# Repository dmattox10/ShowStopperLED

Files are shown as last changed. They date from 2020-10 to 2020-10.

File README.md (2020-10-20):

# ShowStopperLED
A five channel LED strip lighting Controller with serious audio reactivity and many display modes

The Android app communicates over Bluetooth 2.1 with the board, setting modes, and individual settings for each mode.
There is an audio input, which I was really impressed with myself for, because it introduced ZERO noise at all! The audio modes were my absolute favorite.

I stopped working on this project 7 years ago. I got mine working, as well as one for a friend, but a week after I got my prototypes in the mail and assembled them, the competitor released pretty much the same thing, ready for sale, and I gave up.

There are many different iterations, most untested, but the "defiance" version was built, and used successfully, including a $500 traffic ticket because I didn't realize it was on, and it was flashing "Red-Red", "Blue-Blue" on my car, and I got pulled over.

# An Apology: This was all completed and over, before I ever learned about Git!

## Android:
I've included every copy of the source code I have found in my old backups, I didn't compile and test any at this point, since I've switched to iOS personally, and don't have any Android devices lying around. I didn't use or have any apple equipment when I started the project.

## Boards:
I've included every version I made a board for, again, only "defiance" was produced in quantity and tested thoroughly.

## Arduino:
I started with an ATmega328P, moved to a PJRC Teensy 2.0, the code is a mess of files, and I can't tell which one is the "latest" version. The longest iterations are over 2k lines, pretty well commented.

## Media:
All of the files in this directory are photos of the equipment or advertising materials I came up with.

## Demo Links:
I recorded two videos with one of my best friends, of the ShowStopper working, on my 1993 Dodge Stealth.
- [Audio Modes](https://www.youtube.com/watch?v=f9GeiqDAIMo)
- [Motion Modes](https://www.youtube.com/watch?v=yMCRMerskfM)

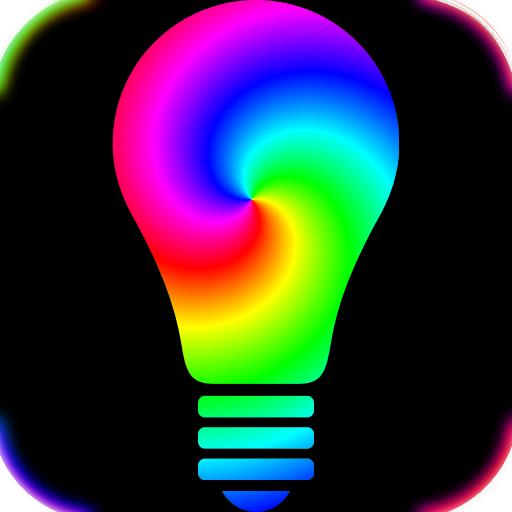
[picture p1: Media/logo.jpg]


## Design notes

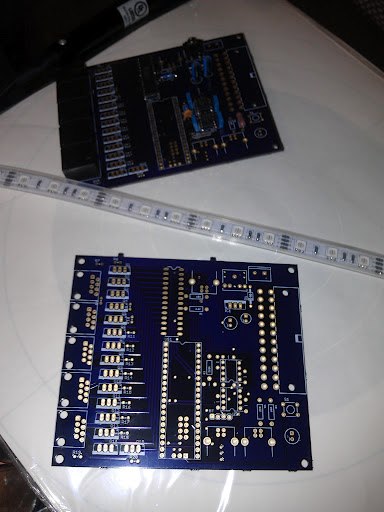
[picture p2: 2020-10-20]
Media/253186_10151097022037730_1391456851_n.jpg

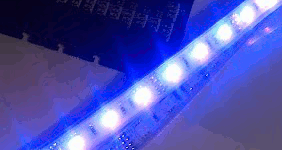
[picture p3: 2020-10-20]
Media/blue.gif

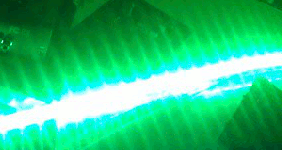
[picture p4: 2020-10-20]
Media/green.gif

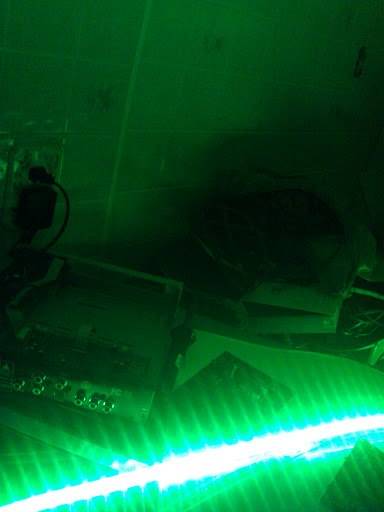
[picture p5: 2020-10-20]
Media/76591_10151097026597730_1787553381_n.jpg

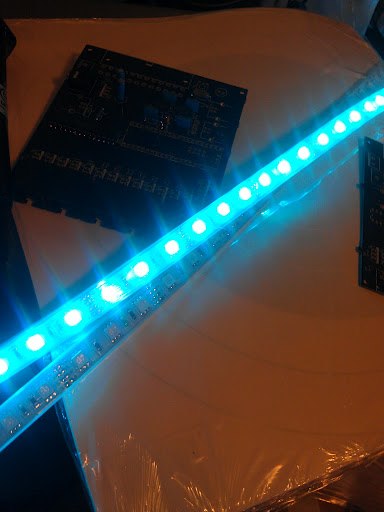
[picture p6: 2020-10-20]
Media/149688_10151097022222730_515309146_n.jpg

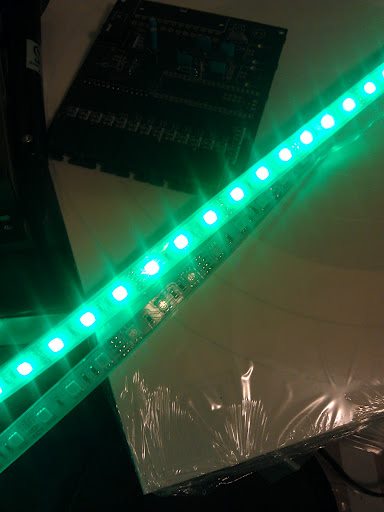
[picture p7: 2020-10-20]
Media/23940_10151097022192730_1112282240_n.jpg

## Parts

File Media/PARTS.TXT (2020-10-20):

Partlist

Exported from ShowStopper REV B.sch at 11/24/2012 2:46:44 PM

EAGLE Version 5.0.0 Copyright (c) 1988-2008 CadSoft

Part     Value                 Device                Package               Library  Sheet

C1       33pf                  CAP0603-CAP           0603-CAP              SparkFun 1
C2       .1uf                  CAP0603-CAP           0603-CAP              SparkFun 1
C3       .01uf                 CAP0603-CAP           0603-CAP              SparkFun 1
C4       .1uf                  CAP0603-CAP           0603-CAP              SparkFun 1
C5       100uf                 CAP_POLPTH1           CPOL-RADIAL-100UF-25V SparkFun 1
C6       10uf                  CAP_POLPTH2           CPOL-RADIAL-10UF-25V  SparkFun 1
C7       .1uf                  CAP0603-CAP           0603-CAP              SparkFun 1
C8       100uf                 CAP_POLPTH1           CPOL-RADIAL-100UF-25V SparkFun 1
C9       22PF                  CAP0805               0805                  SparkFun 1
C10      22PF                  CAP0805               0805                  SparkFun 1
C11      .1uf                  CAP0603-CAP           0603-CAP              SparkFun 1
C12      .1uf                  CAP0603-CAP           0603-CAP              SparkFun 1
C13      .1uf                  CAP0603-CAP           0603-CAP              SparkFun 1
C14      .1uf                  CAP0603-CAP           0603-CAP              SparkFun 1
D1       1N4004                DIODEPTH              DIODE-1N4001          SparkFun 1
EXT      RJ45-8PTH             RJ45-8PTH             RJ45-8                SparkFun 1
IC1      LM7805                V_REG_78XXSINK        TO220-IGO             SparkFun 1
IC2      AVR-MEGA8-PPTH        AVR-MEGA8-PPTH        DIL28-3               SparkFun 1
JP1      BT                    M04LOCK               1X04_LOCK             SparkFun 1
JP2                            M025MM                SCREWTERMINAL-5MM-2   SparkFun 1
JP8                            M06LONGPADS           1X06_LONGPADS         SparkFun 1
JP9                            M02LOCK               1X02_LOCK             SparkFun 1
JP10                           M02LOCK               1X02_LOCK             SparkFun 1
Q1                             MOSFET-NCHANNELPTH2   TO220V                SparkFun 1
Q2                             MOSFET-NCHANNELPTH2   TO220V                SparkFun 1
Q3                             MOSFET-NCHANNELPTH2   TO220V                SparkFun 1
Q4                             MOSFET-NCHANNELPTH2   TO220V                SparkFun 1
Q5                             MOSFET-NCHANNELPTH2   TO220V                SparkFun 1
Q6                             MOSFET-NCHANNELPTH2   TO220V                SparkFun 1
Q7                             MOSFET-NCHANNELPTH2   TO220V                SparkFun 1
Q8                             MOSFET-NCHANNELPTH2   TO220V                SparkFun 1
Q9                             MOSFET-NCHANNELPTH2   TO220V                SparkFun 1
Q10                            MOSFET-NCHANNELPTH2   TO220V                SparkFun 1
Q11                            MOSFET-NCHANNELPTH2   TO220V                SparkFun 1
Q12                            MOSFET-NCHANNELPTH2   TO220V                SparkFun 1
Q14                            MOSFET-NCHANNELPTH2   TO220V                SparkFun 1
Q13                            MOSFET-NCHANNELPTH2   TO220V                SparkFun 1
Q15                            MOSFET-NCHANNELPTH2   TO220V                SparkFun 1
R1       10k                   RESISTOR0805-RES      0805                  SparkFun 1
R2       10k                   RESISTOR0805-RES      0805                  SparkFun 1
R3       10k                   RESISTOR0603-RES      0603-RES              SparkFun 1
R4       10k                   RESISTOR0603-RES      0603-RES              SparkFun 1
R5       10k                   RESISTOR0603-RES      0603-RES              SparkFun 1
R6       10k                   RESISTOR0603-RES      0603-RES              SparkFun 1
R7       10k                   RESISTOR0603-RES      0603-RES              SparkFun 1
R8       10k                   RESISTOR0603-RES      0603-RES              SparkFun 1
R9       10k                   RESISTOR0603-RES      0603-RES              SparkFun 1
R10      10k                   RESISTOR0603-RES      0603-RES              SparkFun 1
R11      10k                   RESISTOR0603-RES      0603-RES              SparkFun 1
R12      10k                   RESISTOR0603-RES      0603-RES              SparkFun 1
R13      10k                   RESISTOR0603-RES      0603-RES              SparkFun 1
R14      10k                   RESISTOR0603-RES      0603-RES              SparkFun 1
R15      10k                   RESISTOR0603-RES      0603-RES              SparkFun 1
R16      10k                   RESISTOR0603-RES      0603-RES              SparkFun 1
R17      10k                   RESISTOR0603-RES      0603-RES              SparkFun 1
R18      200k                  RESISTOR0603-RES      0603-RES              SparkFun 1
R19      22k                   RESISTOR0603-RES      0603-RES              SparkFun 1
R20      22k                   RESISTOR0603-RES      0603-RES              SparkFun 1
R21      2.2K                  RESISTOR0805-RES      0805                  SparkFun 1
S1       SWITCH-MOMENTARY-2PTH SWITCH-MOMENTARY-2PTH TACTILE-PTH           SparkFun 1
U$1      MSGEQ7_PTH            MSGEQ7_PTH            DIL08                 SparkFun 1
U$3      RJ45-8PTH             RJ45-8PTH             RJ45-8                SparkFun 1
U$4      RJ45-8PTH             RJ45-8PTH             RJ45-8                SparkFun 1
U$5      RJ45-8PTH             RJ45-8PTH             RJ45-8                SparkFun 1
U$6      RJ45-8PTH             RJ45-8PTH             RJ45-8                SparkFun 1
U$7      RJ45-8PTH             RJ45-8PTH             RJ45-8                SparkFun 1
U1       AUD0                  AUDIO-JACKPTH         AUDIO-JACK            SparkFun 1
U2       TLC5940-NT            TLC5940-NT            DIL28-3               SparkFun 1
X1       USB_                  USB_                  USB-A-S-SILK-FEMALE   SparkFun 1
Y1       XTAL                  CRYSTALHC49UV         HC49U-V               SparkFun 1

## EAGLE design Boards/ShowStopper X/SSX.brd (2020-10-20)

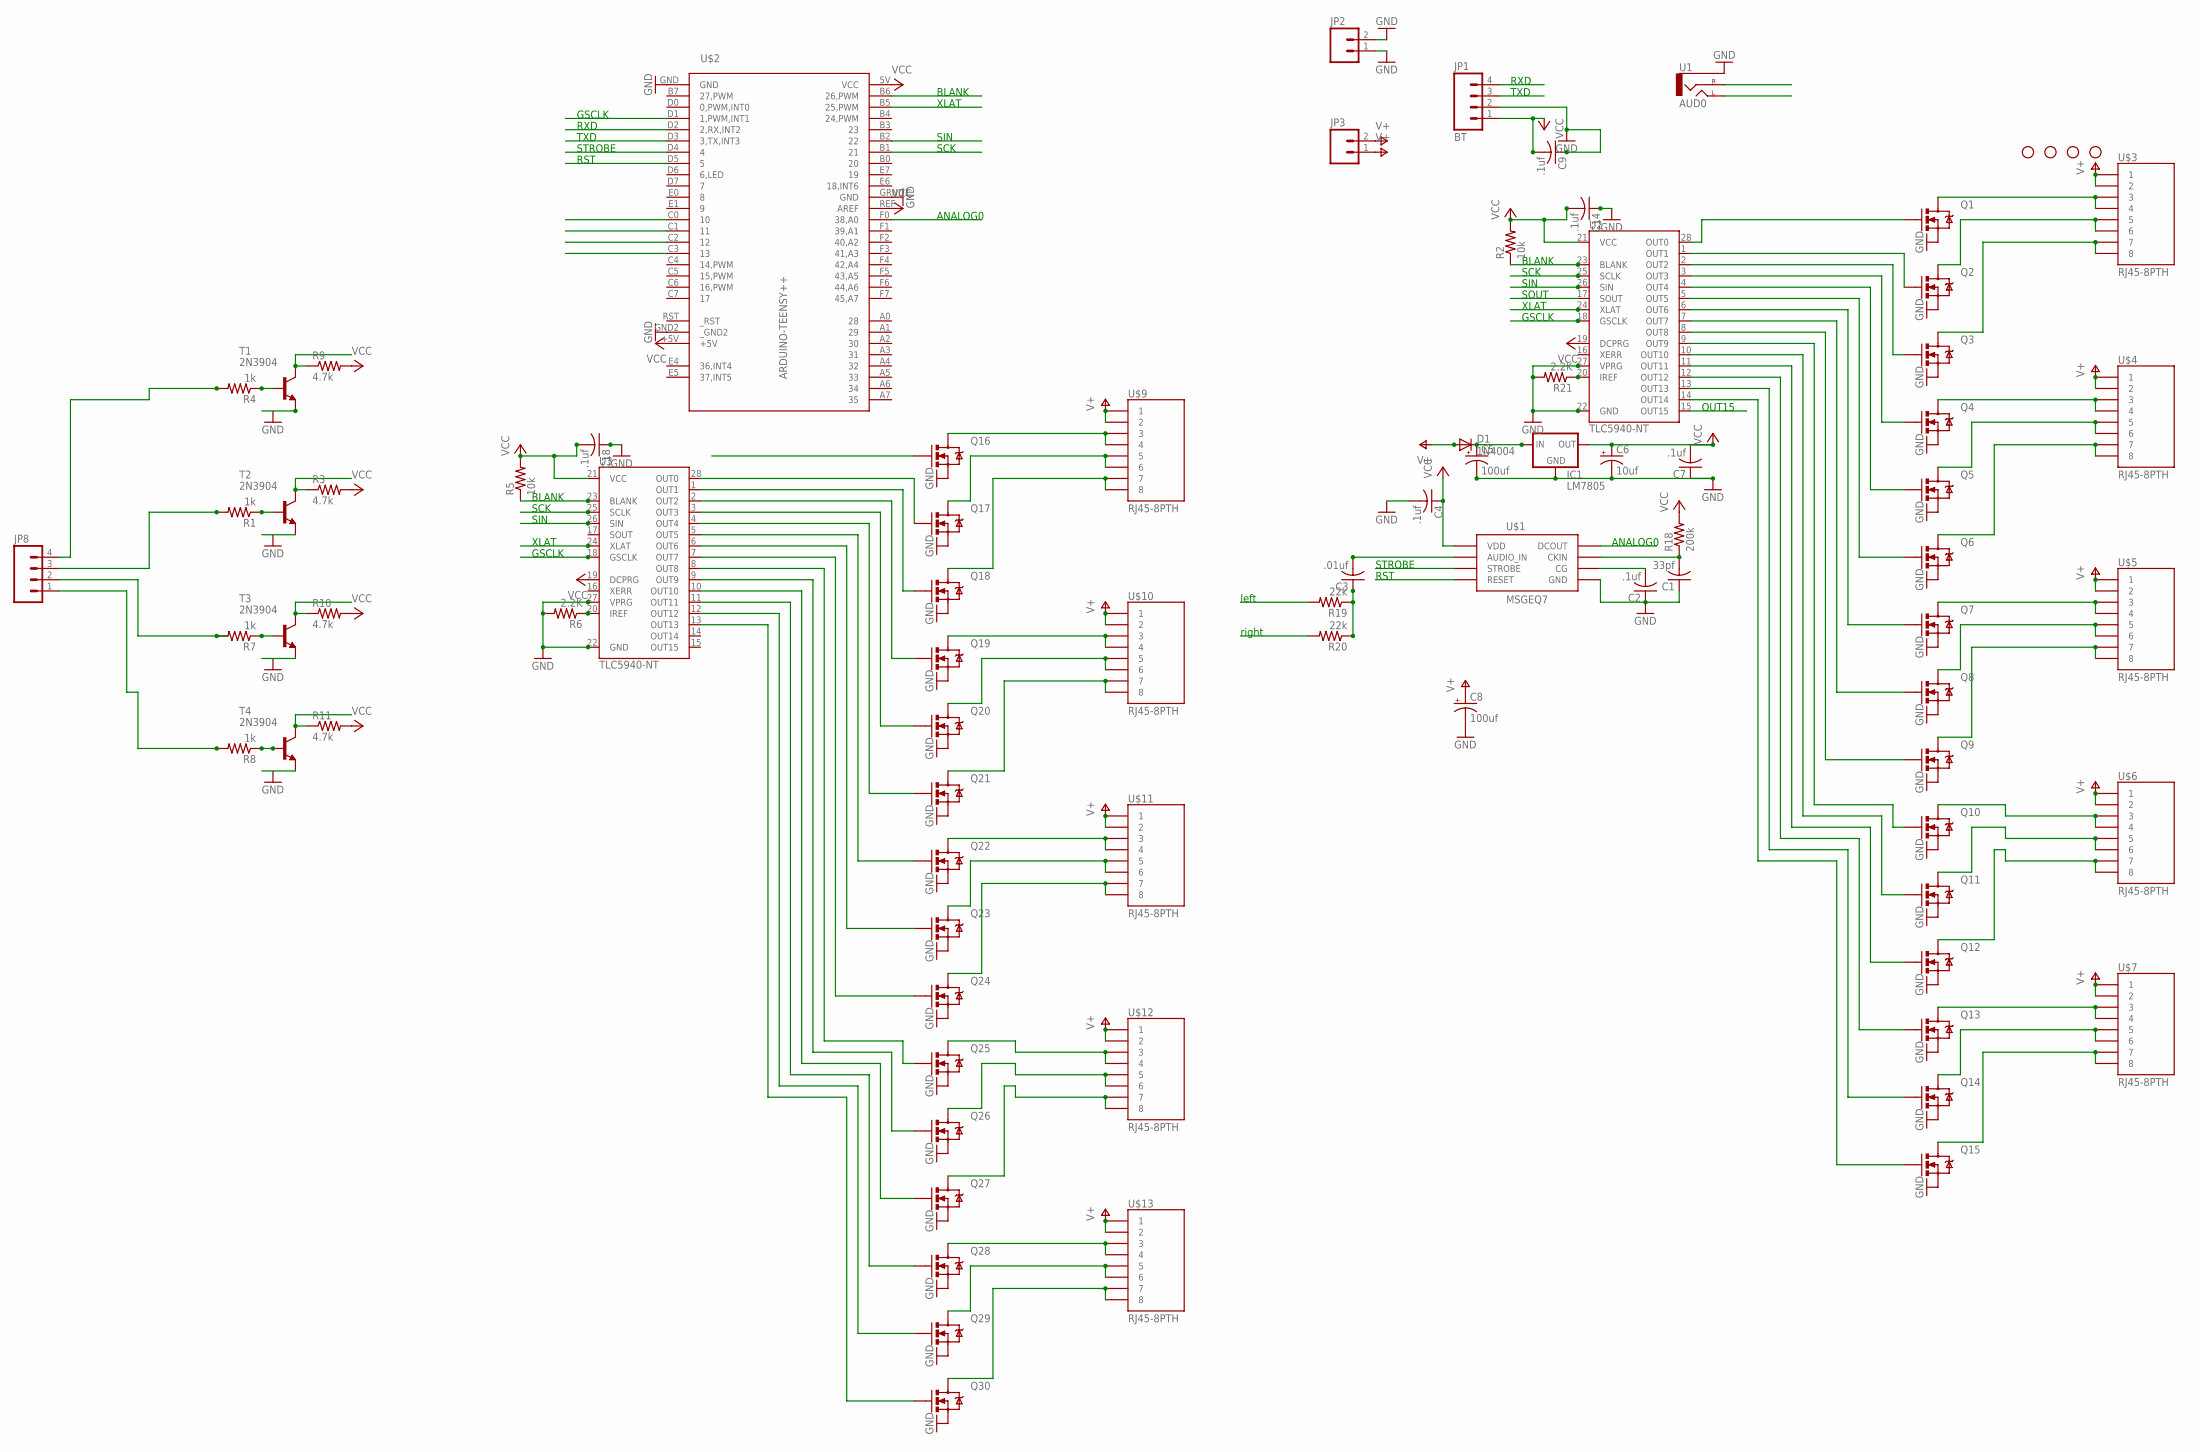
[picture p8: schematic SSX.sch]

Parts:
C1: 33pf; C025-025X050
C2, C4, C7, C9, C14, C18: .1uf; C025-025X050
C3: .01uf; C025-025X050
C5, C8: 100uf; CPOL-RADIAL-100UF-25V
C6: 10uf; CPOL-RADIAL-10UF-25V
D1: 1N4004; DIODE-1N4001
IC1: LM7805; TO220-IGO
JP1: BT; 1X04_LOCK
JP2, JP3: M025MM; SCREWTERMINAL-5MM-2
JP4, JP5, JP6, JP7: STAND-OFF
JP8: M04PTH; 1X04
Q1, Q2, Q3, Q4, Q5, Q6, Q7, Q8, Q9, Q10, Q11, Q12, Q13, Q14, Q15, Q16, Q17, Q18, Q19, Q20, Q21, Q22, Q23, Q24, Q25, Q26, Q27, Q28, Q29, Q30: MOSFET-NCHANNELPTH2; TO220V
R1, R4, R7, R8: 1k; 0207/2V
R2, R5: 10k; 0207/2V
R3, R9, R10, R11: 4.7k; 0207/2V
R6, R21: 2.2K; 0207/2V
R18: 200k; 0207/2V
R19, R20: 22k; 0207/2V
T1, T2, T3, T4: 2N3904; TO92
U1: AUD0; AUDIO-JACK
U2, U3: TLC5940-NT; DIL28-3
U$1: MSGEQ7_PTH; DIL08
U$2: ARDUINO-TEENSY++; TEENSY++
U$3, U$4, U$5, U$6, U$7, U$9, U$10, U$11, U$12, U$13: RJ45-8PTH; RJ45-8

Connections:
ANALOG0: U$1.3 (DCOUT), U$2.F0 (38,A0)
ARS: U$1.7 (RESET), U$2.D5 (5)
BL: R10.1, T3.1 (C), U$2.C1 (11)
BLANK: R2.1, U2.23 (BLANK), U$2.B6 (26,PWM)
BLANK1: R5.1, U3.23 (BLANK)
GND: C1.1, C2.1, C4.2, C5.2 (-), C6.2 (-), C7.1, C8.2 (-), C9.1, C14.1, C18.1, IC1.GND, JP1.2, JP2.1, JP2.2, Q1.3 (S), Q2.3 (S), Q3.3 (S), Q4.3 (S), Q5.3 (S), Q6.3 (S), Q7.3 (S), Q8.3 (S), Q9.3 (S), Q10.3 (S), Q11.3 (S), Q12.3 (S), Q13.3 (S), Q14.3 (S), Q15.3 (S), Q16.3 (S), Q17.3 (S), Q18.3 (S), Q19.3 (S), Q20.3 (S), Q21.3 (S), Q22.3 (S), Q23.3 (S), Q24.3 (S), Q25.3 (S), Q26.3 (S), Q27.3 (S), Q28.3 (S), Q29.3 (S), Q30.3 (S), R6.2, R21.2, U1.SLEEVE, U2.22 (GND), U2.27 (VPRG), U3.22 (GND), U3.27 (VPRG), U$1.2 (GND), U$2.GND, U$2.GND2 (_GND2), U$2.GRND1 (GND)
GSCLK: U2.18 (GSCLK), U$2.D1 (1,PWM,INT1)
GSCLK1: U3.18 (GSCLK)
HL: R11.1, T4.1 (C), U$2.C0 (10)
LEFT: R19.2, U1.TIP (LEFT)
LTS: R3.1, T2.1 (C), U$2.C2 (12)
unnamed: Q7.2 (D), U$5.3, U$5.4
unnamed: Q2.2 (D), U$3.5, U$3.6
unnamed: Q3.2 (D), U$3.7, U$3.8
unnamed: Q10.2 (D), U$6.3, U$6.4
unnamed: Q9.1 (G), U2.8 (OUT8)
unnamed: Q2.1 (G), U2.1 (OUT1)
unnamed: Q3.1 (G), U2.2 (OUT2)
unnamed: Q4.1 (G), U2.3 (OUT3)
unnamed: Q5.2 (D), U$4.5, U$4.6
unnamed: Q5.1 (G), U2.4 (OUT4)
unnamed: Q6.1 (G), U2.5 (OUT5)
unnamed: Q7.1 (G), U2.6 (OUT6)
unnamed: Q8.1 (G), U2.7 (OUT7)
unnamed: Q17.1 (G), U3.28 (OUT0)
unnamed: Q10.1 (G), U2.9 (OUT9)
unnamed: Q11.1 (G), U2.10 (OUT10)
unnamed: Q12.1 (G), U2.11 (OUT11)
unnamed: Q13.1 (G), U2.12 (OUT12)
unnamed: Q14.1 (G), U2.13 (OUT13)
unnamed: Q15.1 (G), U2.14 (OUT14)
unnamed: Q6.2 (D), U$4.7, U$4.8
unnamed: Q13.2 (D), U$7.3, U$7.4
unnamed: Q8.2 (D), U$5.5, U$5.6
unnamed: C1.2, R18.1, U$1.8 (CKIN)
unnamed: Q9.2 (D), U$5.7, U$5.8
unnamed: Q14.2 (D), U$7.5, U$7.6
unnamed: Q11.2 (D), U$6.5, U$6.6
unnamed: C3.2, U$1.5 (AUDIO_IN)
unnamed: Q12.2 (D), U$6.7, U$6.8
unnamed: Q15.2 (D), U$7.7, U$7.8
unnamed: Q1.2 (D), U$3.3, U$3.4
unnamed: C2.2, U$1.6 (CG)
unnamed: Q4.2 (D), U$4.3, U$4.4
unnamed: Q1.1 (G), U2.28 (OUT0)
unnamed: R21.1, U2.20 (IREF)
unnamed: C3.1, R19.1, R20.1
unnamed: Q18.1 (G), U3.1 (OUT1)
unnamed: Q19.1 (G), U3.2 (OUT2)
unnamed: Q20.1 (G), U3.3 (OUT3)
unnamed: C5.1 (+), D1.C, IC1.IN
unnamed: Q21.1 (G), U3.4 (OUT4)
unnamed: Q22.1 (G), U3.5 (OUT5)
unnamed: Q23.1 (G), U3.6 (OUT6)
unnamed: Q25.1 (G), U3.8 (OUT8)
unnamed: Q26.1 (G), U3.9 (OUT9)
unnamed: Q27.1 (G), U3.10 (OUT10)
unnamed: Q28.1 (G), U3.11 (OUT11)
unnamed: Q29.1 (G), U3.12 (OUT12)
unnamed: Q30.1 (G), U3.13 (OUT13)
unnamed: R1.1, T2.2 (B)
unnamed: Q17.2 (D), U$9.5, U$9.6
unnamed: Q18.2 (D), U$9.7, U$9.8
unnamed: Q20.2 (D), U$10.5, U$10.6
unnamed: Q21.2 (D), U$10.7, U$10.8
unnamed: Q23.2 (D), U$11.5, U$11.6
unnamed: Q24.2 (D), U$11.7, U$11.8
unnamed: Q26.2 (D), U$12.5, U$12.6
unnamed: Q27.2 (D), U$12.7, U$12.8
unnamed: Q16.2 (D), U$9.3, U$9.4
unnamed: Q19.2 (D), U$10.3, U$10.4
unnamed: Q22.2 (D), U$11.3, U$11.4
unnamed: Q25.2 (D), U$12.3, U$12.4
unnamed: Q28.2 (D), U$13.3, U$13.4
unnamed: Q29.2 (D), U$13.5, U$13.6
unnamed: Q30.2 (D), U$13.7, U$13.8
unnamed: R4.1, T1.2 (B)
unnamed: Q24.1 (G), U3.7 (OUT7)
unnamed: R6.1, U3.20 (IREF)
unnamed: R7.1, T3.2 (B)
unnamed: R8.1, T4.2 (B)
unnamed: JP8.4, R4.2
unnamed: JP8.3, R1.2
unnamed: JP8.2, R7.2
unnamed: JP8.1, R8.2
OUT15: Q16.1 (G), U2.15 (OUT15)
RIGHT: R20.2, U1.RING (RIGHT)
RTS: R9.1, T1.1 (C), U$2.C3 (13)
RXD: JP1.4, U$2.D3 (3,TX,INT3)
SCK: U2.25 (SCLK), U$2.B1 (21)
SCK1: U3.25 (SCLK)
SIN: U2.26 (SIN), U$2.B2 (22)
SOUT: U2.17 (SOUT), U3.26 (SIN)
STROBE: U$1.4 (STROBE), U$2.D4 (4)
TXD: JP1.3, U$2.D2 (2,RX,INT2)
V+: C8.1 (+), D1.A, JP3.1, JP3.2, U$3.1, U$3.2, U$4.1, U$4.2, U$5.1, U$5.2, U$6.1, U$6.2, U$7.1, U$7.2, U$9.1, U$9.2, U$10.1, U$10.2, U$11.1, U$11.2, U$12.1, U$12.2, U$13.1, U$13.2
VCC: C4.1, C6.1 (+), C7.2, C9.2, C14.2, C18.2, IC1.OUT, JP1.1, R2.2, R3.2, R5.2, R9.2, R10.2, R11.2, R18.2, U2.19 (DCPRG), U2.21 (VCC), U3.19 (DCPRG), U3.21 (VCC), U$1.1 (VDD), U$2.5V (VCC), U$2.+5V, U$2.REF (AREF)
XLAT: U2.24 (XLAT), U$2.B5 (25,PWM)
XLAT1: U3.24 (XLAT)

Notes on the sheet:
ANALOG0
RST
STROBE
left
right
SIN
SCK
XLAT
BLANK
GSCLK
RXD
TXD
SOUT
OUT15

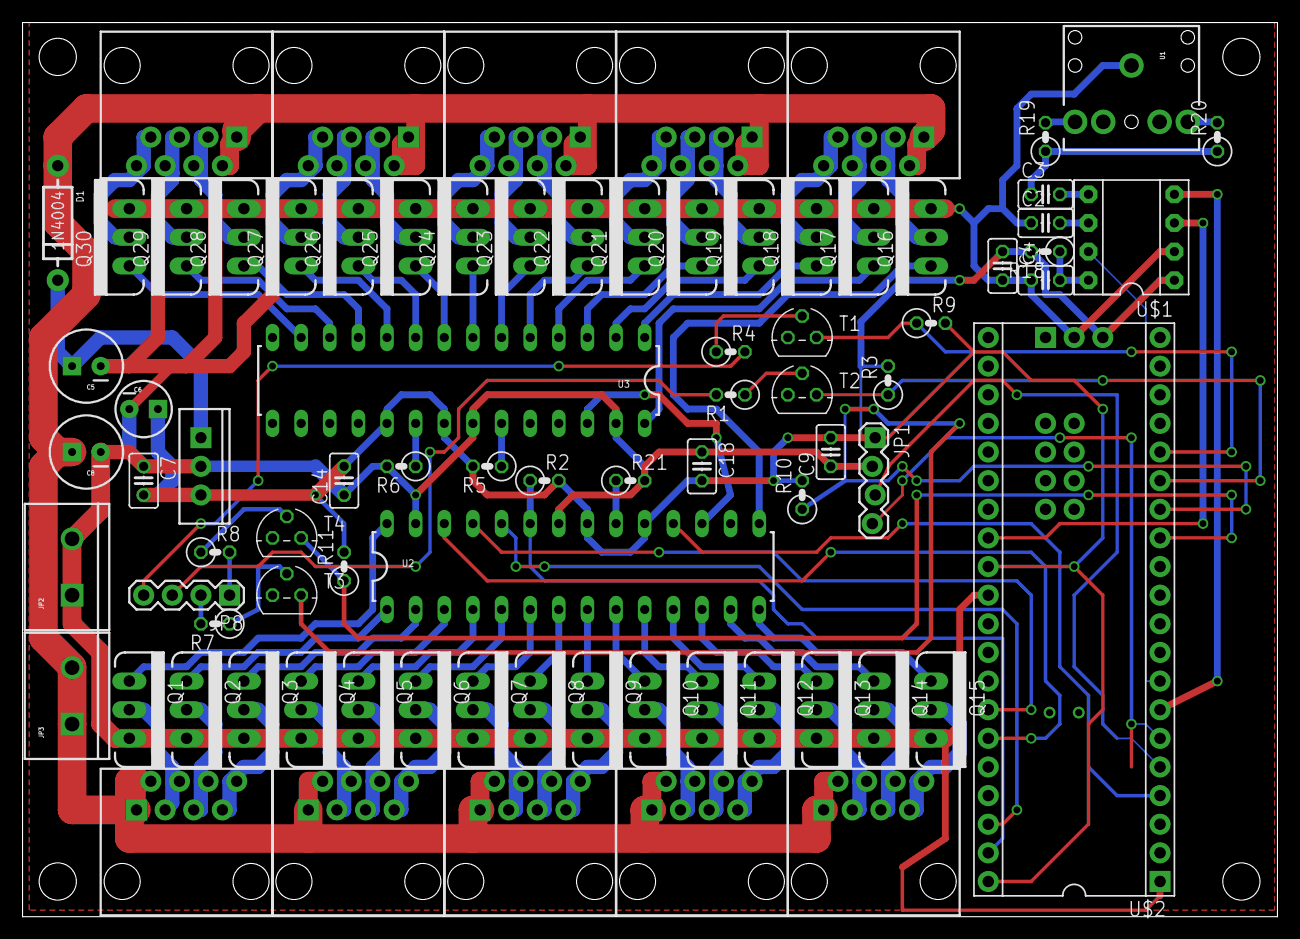
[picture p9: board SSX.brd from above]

Board: 2 copper layers, 111.3 x 79.3 mm, 85 parts (0 on the bottom side), 96 nets.

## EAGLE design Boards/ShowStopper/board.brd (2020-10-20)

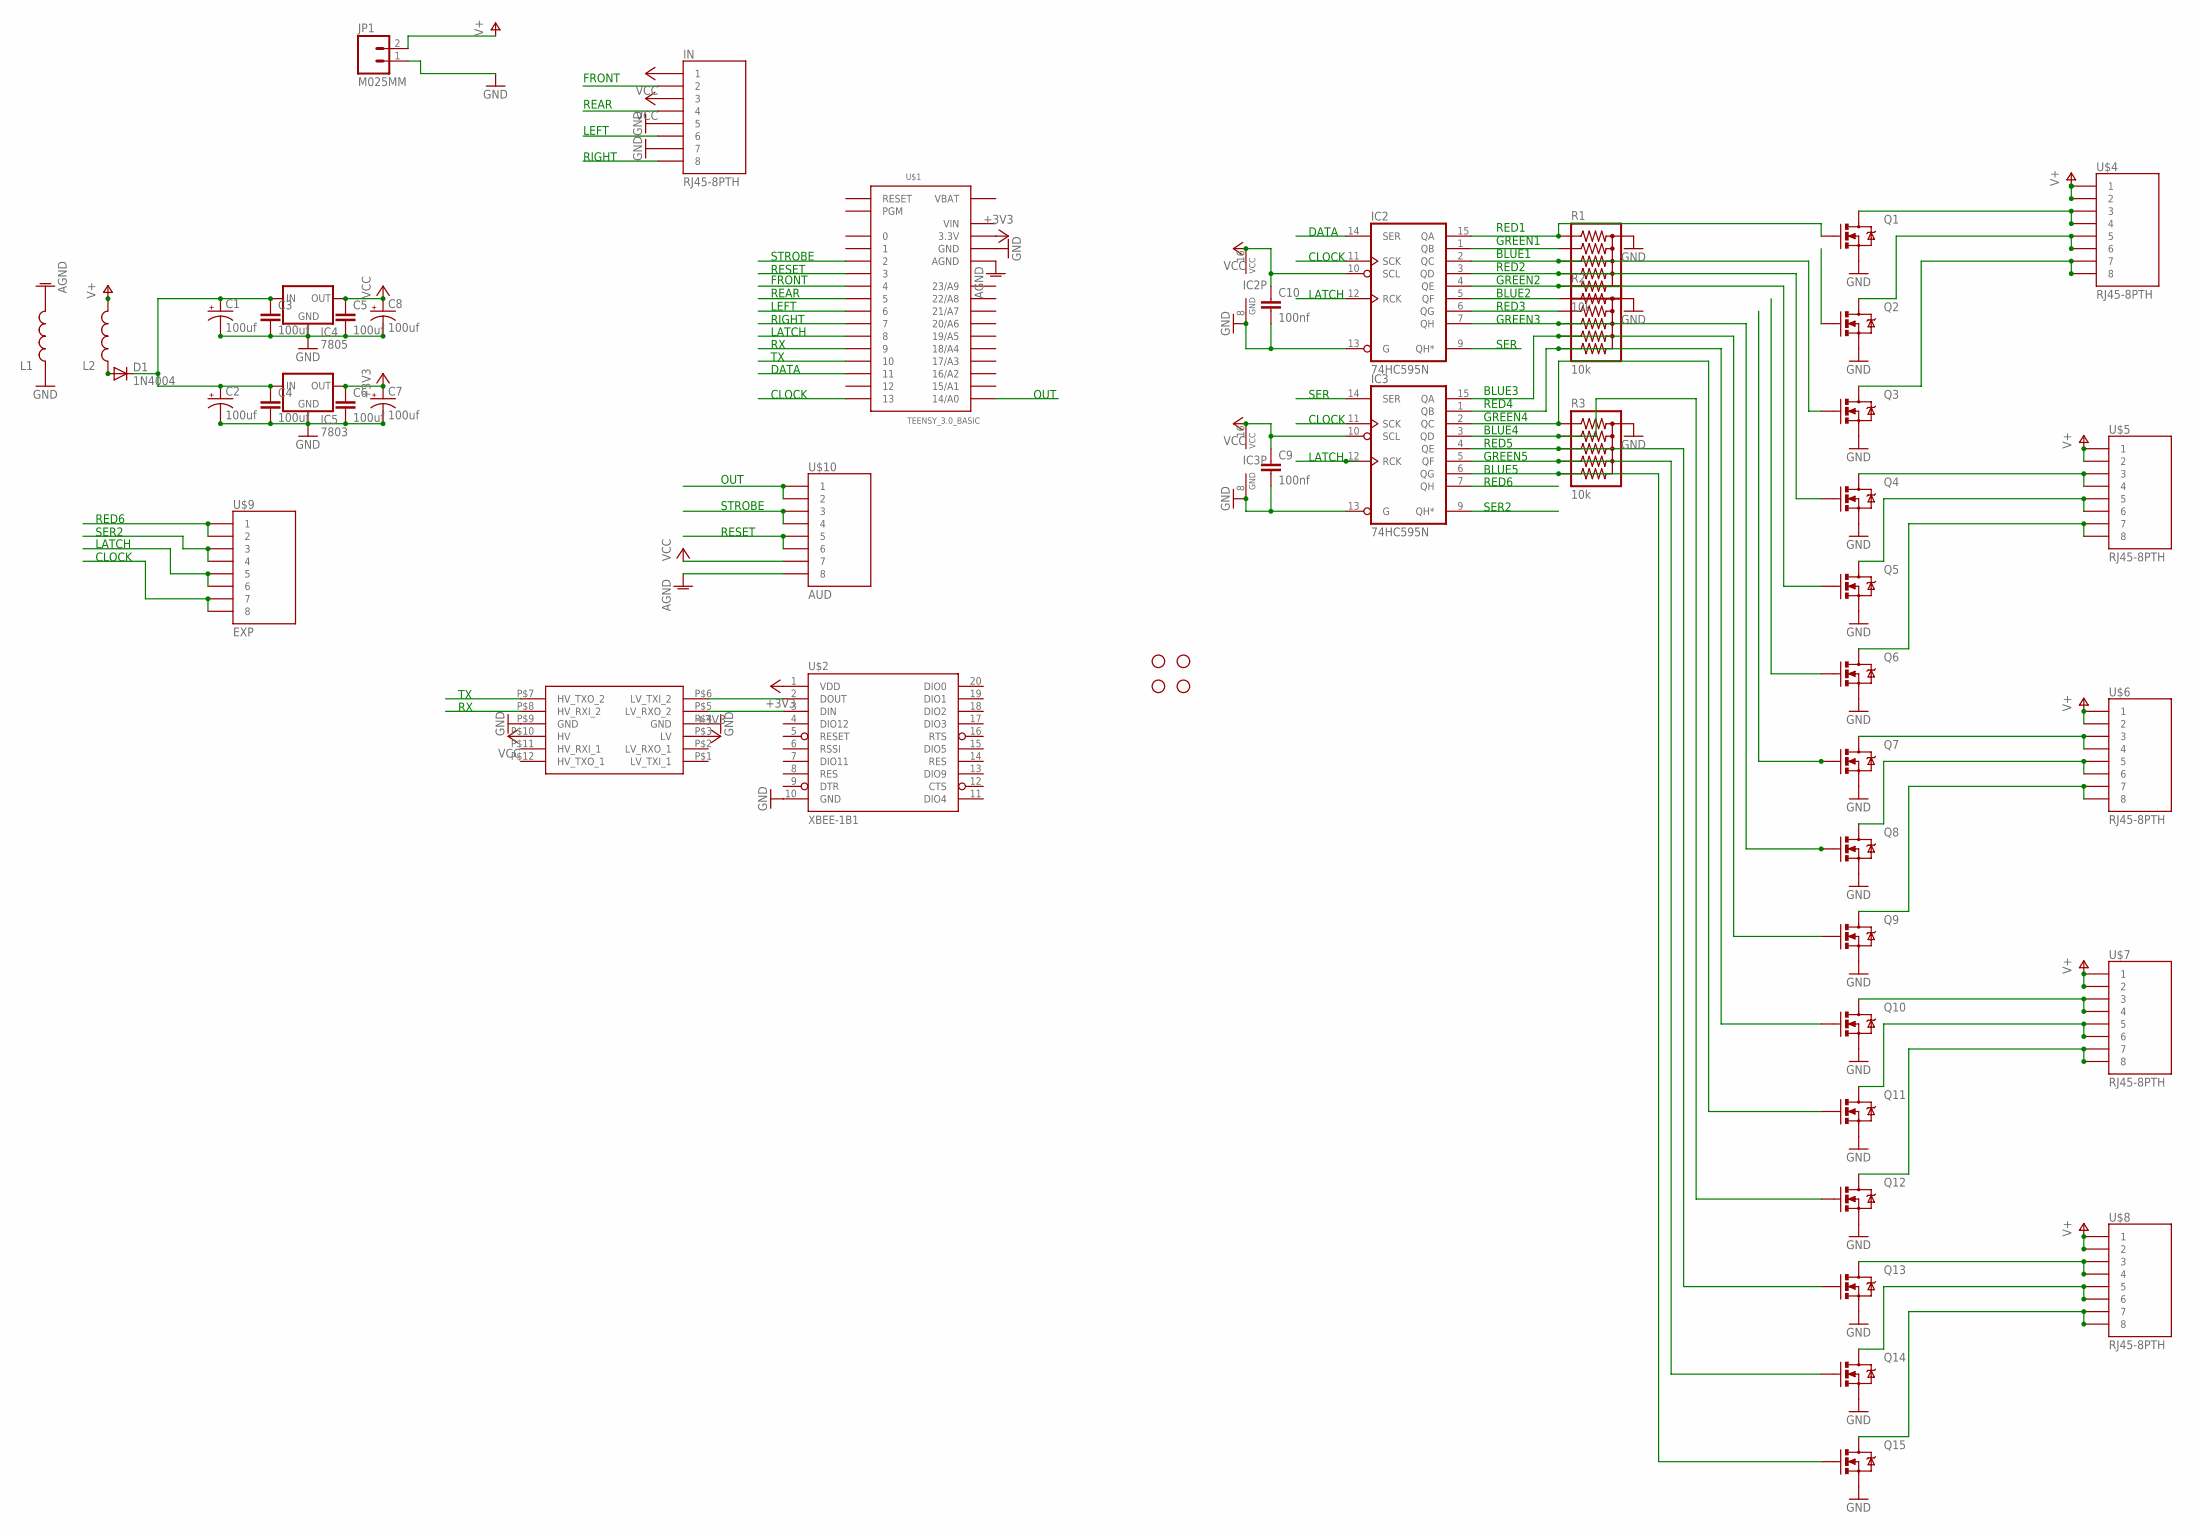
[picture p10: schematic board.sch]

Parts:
C1, C2, C7, C8: 100uf; CPOL-RADIAL-100UF-25V
C3, C4, C5, C6: 100uf; CAP-PTH-SMALL
C9, C10: 100nf; CAP-PTH-SMALL
D1: 1N4004; DO41-10
IC2, IC3: 74HC595N; DIL16
IC4: 7805; TO220-IGO
IC5: 7803; 78XXL
IN: RJ45-8PTH; RJ45-8
JP1: M025MM; SCREWTERMINAL-5MM-2
L1, L2: INDUCTORRLB0912; RLB0912
Q1, Q2, Q3, Q4, Q5, Q6, Q7, Q8, Q9, Q10, Q11, Q12, Q13, Q14, Q15: MOSFET-NCHANNELFQP30N06L; TO220V
R1, R2, R3: 10k; RPACK-SIP-PTH-5
STANDOFF1, STANDOFF2, STANDOFF3, STANDOFF4: STAND-OFF
U$1: TEENSY_3.0_BASIC
U$2: XBEE-1B1; XBEE-1
U$3: LOGIC_LEVEL_CONVERTER
U$4, U$5, U$6, U$7, U$8: RJ45-8PTH; RJ45-8
U$9: EXP; RJ45-8
U$10: AUD; RJ45-8

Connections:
+3V3: C6.1, C7.1 (+), IC5.GND (OUT), U$1.3.3V, U$1.3.3V1 (3.3V), U$2.1 (VDD), U$3.P$3 (LV)
AGND: L1.2, U$1.AGND, U$10.8
BLUE1: IC2.2 (QC), Q3.1 (G), R1.P$4 (4)
BLUE2: IC2.5 (QF), Q6.1 (G), R2.P$2 (2)
BLUE3: IC3.15 (QA), Q9.1 (G), R2.P$5 (5)
BLUE4: IC3.3 (QD), Q12.1 (G), R3.P$3 (3)
BLUE5: IC3.6 (QG), Q15.1 (G), R3.P$6 (6)
CLOCK: IC2.11 (SCK), IC3.11 (SCK), U$1.13, U$9.7, U$9.8
DATA: IC2.14 (SER), U$1.11
FRONT: IN.2, U$1.4
GND: C1.2 (-), C2.2 (-), C3.2, C4.2, C5.2, C6.2, C7.2 (-), C8.2 (-), C9.2, C10.2, IC2.8 (GND), IC2.13 (G), IC3.8 (GND), IC3.13 (G), IC4.GND, IC5.IN (GND), IN.5, IN.7, JP1.1, L1.1, Q1.3 (S), Q2.3 (S), Q3.3 (S), Q4.3 (S), Q5.3 (S), Q6.3 (S), Q7.3 (S), Q8.3 (S), Q9.3 (S), Q10.3 (S), Q11.3 (S), Q12.3 (S), Q13.3 (S), Q14.3 (S), Q15.3 (S), R1.P$1 (1), R2.P$1 (1), R3.P$1 (1), U$1.GND, U$1.GND1 (GND), U$2.10 (GND), U$3.P$4 (GND), U$3.P$9 (GND)
GREEN1: IC2.1 (QB), Q2.1 (G), R1.P$3 (3)
GREEN2: IC2.4 (QE), Q5.1 (G), R1.P$6 (6)
GREEN3: IC2.7 (QH), Q8.1 (G), R2.P$4 (4)
GREEN4: IC3.2 (QC), Q11.1 (G), R3.P$2 (2)
GREEN5: IC3.5 (QF), Q14.1 (G), R3.P$5 (5)
LATCH: IC2.12 (RCK), IC3.12 (RCK), U$1.8, U$9.5, U$9.6
LEFT: IN.6, U$1.6
unnamed: Q3.2 (D), U$4.7, U$4.8
unnamed: D1.A, L2.1
unnamed: Q4.2 (D), U$5.3, U$5.4
unnamed: Q5.2 (D), U$5.5, U$5.6
unnamed: Q6.2 (D), U$5.7, U$5.8
unnamed: C1.1 (+), C2.1 (+), C3.1, C4.1, D1.C, IC4.IN, IC5.OUT (IN)
unnamed: Q7.2 (D), U$6.3, U$6.4
unnamed: Q8.2 (D), U$6.5, U$6.6
unnamed: Q9.2 (D), U$6.7, U$6.8
unnamed: Q10.2 (D), U$7.3, U$7.4
unnamed: Q11.2 (D), U$7.5, U$7.6
unnamed: Q12.2 (D), U$7.7, U$7.8
unnamed: Q13.2 (D), U$8.3, U$8.4
unnamed: Q14.2 (D), U$8.5, U$8.6
unnamed: Q15.2 (D), U$8.7, U$8.8
unnamed: Q1.2 (D), U$4.3, U$4.4
unnamed: Q2.2 (D), U$4.5, U$4.6
unnamed: U$2.3 (DIN), U$3.P$5 (LV_RXO_2)
unnamed: U$2.2 (DOUT), U$3.P$6 (LV_TXI_2)
OUT: U$1.14/A0, U$10.1, U$10.2
REAR: IN.4, U$1.5
RED1: IC2.15 (QA), Q1.1 (G), R1.P$2 (2)
RED2: IC2.3 (QD), Q4.1 (G), R1.P$5 (5)
RED3: IC2.6 (QG), Q7.1 (G), R2.P$3 (3)
RED4: IC3.1 (QB), Q10.1 (G), R2.P$6 (6)
RED5: IC3.4 (QE), Q13.1 (G), R3.P$4 (4)
RED6: IC3.7 (QH), U$9.1, U$9.2
RESET: U$1.3, U$10.5, U$10.6
RIGHT: IN.8, U$1.7
RX: U$1.9, U$3.P$7 (HV_TXO_2)
SER: IC2.9 (QH*), IC3.14 (SER)
SER2: IC3.9 (QH*), U$9.3, U$9.4
STROBE: U$1.2, U$10.3, U$10.4
TX: U$1.10, U$3.P$8 (HV_RXI_2)
V+: JP1.2, L2.2, U$4.1, U$4.2, U$5.1, U$5.2, U$6.1, U$6.2, U$7.1, U$7.2, U$8.1, U$8.2
VBAT: U$1.VBAT
VCC: C5.1, C8.1 (+), C9.1, C10.1, IC2.10 (SCL), IC2.16 (VCC), IC3.10 (SCL), IC3.16 (VCC), IC4.OUT, IN.1, IN.3, U$3.P$10 (HV), U$10.7
VIN: U$1.VIN

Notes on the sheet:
RED1 GREEN1 BLUE1 RED2 GREEN2 BLUE2 RED3 GREEN3
BLUE3 RED4 GREEN4 BLUE4 RED5 GREEN5 BLUE5
DATA
CLOCK
LATCH
SER
STROBE RESET
OUT
RED6
SER2
RED6 SER2
FRONT REAR LEFT RIGHT
LATCH CLOCK
OUT STROBE RESET
FRONT REAR LEFT RIGHT

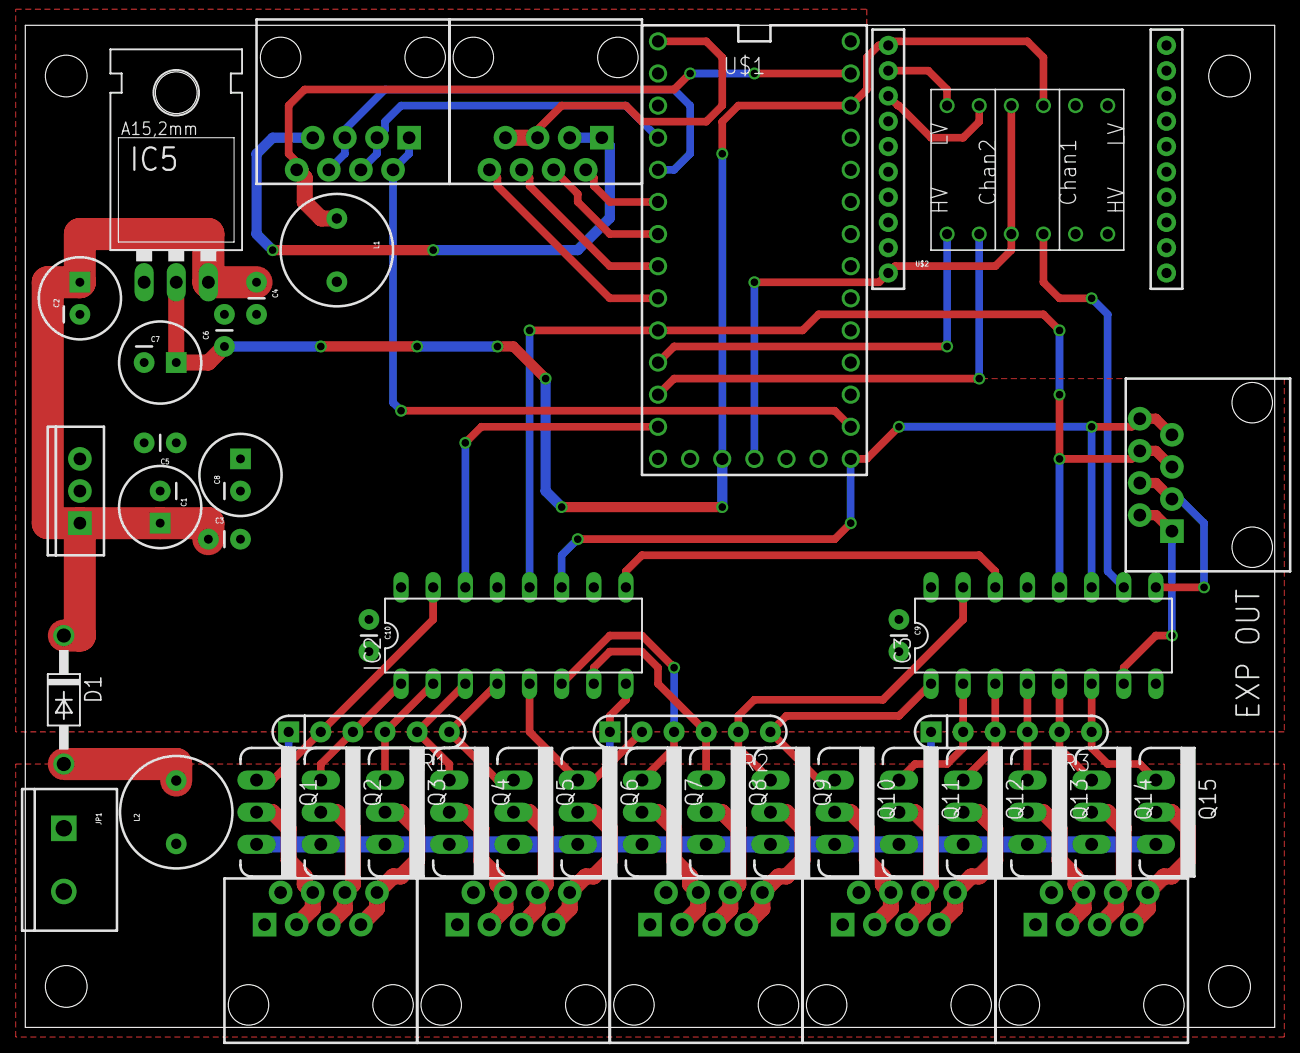
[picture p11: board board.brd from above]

Board: 2 copper layers, 98.8 x 79.2 mm, 51 parts (0 on the bottom side), 54 nets.

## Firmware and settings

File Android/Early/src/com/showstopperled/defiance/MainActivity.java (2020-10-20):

package com.showstopperled.defiance;

import java.io.BufferedReader;
import java.io.File;
import java.io.FileInputStream;
import java.io.FileNotFoundException;
import java.io.IOException;
import java.io.InputStreamReader;
import java.io.OutputStream;
import java.util.Random;
import java.util.UUID;

import android.app.Activity;
import android.bluetooth.BluetoothAdapter;
import android.bluetooth.BluetoothDevice;
import android.bluetooth.BluetoothSocket;
import android.content.SharedPreferences;
import android.graphics.Color;
import android.os.Bundle;
import android.os.Environment;
import android.view.View;
import android.widget.AdapterView;
import android.widget.SeekBar;
import android.widget.SeekBar.OnSeekBarChangeListener;
import android.widget.Spinner;
import android.widget.TextView;
import android.widget.Toast;
import com.showstopperled.defiance.ColorPickerDialog.OnColorChangedListener;

	public class MainActivity extends Activity implements OnColorChangedListener
		{
		public static final String PREFS_NAME = "DefiancePrefsFile";
		static String Packet = null;
		private BluetoothAdapter mBluetoothAdapter = null;
		private BluetoothSocket btSocket = null;
		private static OutputStream outStream = null;
		
		SeekBar seekbarUnicorns, seekbarChan, seekbarRed, seekbarGreen, seekbarBlue, seekbarBand, seekbarSens;
		TextView valueUnicorns, valueChan, valueRed, valueGreen, valueBlue, valueBand, valueSens, valueSave;
		static int Channel = 0;
		static int Rset = 255;
		static int Gset = 0;
		static int Bset = 0;
		static int Mode = 0;
		static int Band = 0;
		static int Sens = 24;
		static int Save = 0;
		static int Unicorns = 0;
	
	String audB = "63Hz";
	
	private static final UUID MY_UUID = UUID
			.fromString("00001101-0000-1000-8000-00805F9B34FB");

	// hardcoded MAC address
	private static String address = null;
	private BufferedReader buf;

	public void onCreate(Bundle savedInstanceState) {
		super.onCreate(savedInstanceState);
		setContentView(R.layout.activity_main);
        
        SharedPreferences settings = getSharedPreferences(PREFS_NAME, 0);
        
        valueChan = (TextView) findViewById(R.id.textViewChan);
		seekbarChan = (SeekBar) findViewById(R.id.seekBarChan);
		valueRed = (TextView) findViewById(R.id.textViewRed);
		seekbarRed = (SeekBar) findViewById(R.id.seekBarRed);
		valueGreen = (TextView) findViewById(R.id.textViewGreen);
		seekbarGreen = (SeekBar) findViewById(R.id.seekBarGreen);
		valueBlue = (TextView) findViewById(R.id.textViewBlue);
		seekbarBlue = (SeekBar) findViewById(R.id.seekBarBlue);
		valueBand = (TextView) findViewById(R.id.textViewBand);
		seekbarBand = (SeekBar) findViewById(R.id.seekBarBand);
		valueSens = (TextView) findViewById(R.id.textViewSens);
		seekbarSens = (SeekBar) findViewById(R.id.seekBarSens);
		valueUnicorns = (TextView) findViewById(R.id.textViewUnicorns);
		seekbarUnicorns = (SeekBar) findViewById(R.id.seekBarUnicorns);
		
		Spinner s = (Spinner) findViewById(R.id.spinnerMode);
		s.setOnItemSelectedListener(new AdapterView.OnItemSelectedListener(){
		 
		public void onItemSelected(AdapterView<?> adapter, View v, int i, long lng) {
		Mode = i;
		packet(Channel, Rset, Gset, Bset, Mode, Band, Sens, Unicorns, Save);
		}
		 
		public void onNothingSelected(AdapterView<?> arg0) {
		//do something else
		}
		});
		
		mBluetoothAdapter = BluetoothAdapter.getDefaultAdapter();
		if (mBluetoothAdapter == null) {
			Toast.makeText(this, "Bluetooth is not available.",
					Toast.LENGTH_LONG).show();
			finish();
			return;
		}

		if (!mBluetoothAdapter.isEnabled()) {
			Toast.makeText(this,
					"Please enable your BT and re-run this program.",
					Toast.LENGTH_LONG).show();
			finish();
			return;
		}

		int sbar_chan_position = settings.getInt("seekbar_chan_pref", 0);
		seekbarChan.setProgress(sbar_chan_position);
		valueChan.setText("Channel: " + sbar_chan_position);
		Channel = sbar_chan_position;
		
		int sbar_red_position = settings.getInt("seekbar_red_pref", 0);
		seekbarRed.setProgress(sbar_red_position);
		valueRed.setText("Red: " + sbar_red_position);
		Rset = sbar_red_position;
		
		int sbar_green_position = settings.getInt("seekbar_green_pref", 0);
		seekbarGreen.setProgress(sbar_green_position);
		valueGreen.setText("Green: " + sbar_green_position);
		Gset = sbar_green_position;
		
		int sbar_blue_position = settings.getInt("seekbar_blue_pref", 0);
		seekbarBlue.setProgress(sbar_blue_position);
		valueBlue.setText("Blue: " + sbar_blue_position);
		Bset = sbar_blue_position;
		
		int sbar_band_position = settings.getInt("seekbar_band_pref", 0);
		seekbarBand.setProgress(sbar_band_position);
		valueBand.setText("Band: " + sbar_band_position);
		Band = sbar_band_position;
		
		int sbar_sens_position = settings.getInt("seekbar_sens_pref", 0);
		seekbarSens.setProgress(sbar_sens_position);
		valueSens.setText("Sensitivity: " + sbar_sens_position);
		Sens = sbar_sens_position;
		
		int sbar_unicorns_position = settings.getInt("seekbar_unicorns_pref", 0);
		seekbarUnicorns.setProgress(sbar_unicorns_position);
		valueUnicorns.setText("Unicorns!: " + sbar_unicorns_position);
		Unicorns = sbar_unicorns_position;
		
		seekbarChan.setOnSeekBarChangeListener(new OnSeekBarChangeListener() {
			public void onProgressChanged(SeekBar seekBar, int progress,
					boolean fromUser) {
				valueChan.setText("Channel: " + (progress + 1));
				Channel = progress;
				packet(Channel, Rset, Gset, Bset, Mode, Band, Sens, Unicorns, Save);
				

			}
			public void onStartTrackingTouch(SeekBar seekBar) {
				// TODO Auto-generated method stub
			}

			public void onStopTrackingTouch(SeekBar seekBar) {
				// TODO Auto-generated method stub
			}
		});
			
seekbarRed.setOnSeekBarChangeListener(new OnSeekBarChangeListener() {
			public void onProgressChanged(SeekBar seekBar, int progress,
					boolean fromUser) {
				valueRed.setText("Red: " + progress);

				Rset = progress;
				packet(Channel, Rset, Gset, Bset, Mode, Band, Sens, Unicorns, Save);

			}
			public void onStartTrackingTouch(SeekBar seekBar) {
				// TODO Auto-generated method stub
			}

			public void onStopTrackingTouch(SeekBar seekBar) {
				// TODO Auto-generated method stub
			}
		});
			
seekbarGreen.setOnSeekBarChangeListener(new OnSeekBarChangeListener() {
			public void onProgressChanged(SeekBar seekBar, int progress,
					boolean fromUser) {
				valueGreen.setText("Green: " + progress);

				Gset = progress;
				packet(Channel, Rset, Gset, Bset, Mode, Band, Sens, Unicorns, Save);


			}
			public void onStartTrackingTouch(SeekBar seekBar) {
				// TODO Auto-generated method stub
			}

			public void onStopTrackingTouch(SeekBar seekBar) {
				// TODO Auto-generated method stub
			}
		});
			
seekbarBlue.setOnSeekBarChangeListener(new OnSeekBarChangeListener() {
			public void onProgressChanged(SeekBar seekBar, int progress,
					boolean fromUser) {
				valueBlue.setText("Blue: " + progress);

				Bset = progress;
				packet(Channel, Rset, Gset, Bset, Mode, Band, Sens, Unicorns, Save);

			}
			
			public void onStartTrackingTouch(SeekBar seekBar) {
				// TODO Auto-generated method stub
			}

			public void onStopTrackingTouch(SeekBar seekBar) {
				// TODO Auto-generated method stub
			}
		});
			
seekbarBand.setOnSeekBarChangeListener(new OnSeekBarChangeListener() {
			public void onProgressChanged(SeekBar seekBar, int progress,
					boolean fromUser) {
					switch(progress)
					{
					case 0:
					audB = "63Hz";
					break;
					case 1:
					audB = "160Hz";
					break;
					case 2:
					audB = "400Hz";
					break;
					case 3:
					audB = "1kHz";
					break;
					case 4:
					audB = "2.5kHz";
					break;
					case 5:
					audB = "6.25kHz";
					break;
					case 6:
					audB = "16kHz";
					break;
					}
				valueBand.setText("Band: " + audB);

				Band = progress;
				packet(Channel, Rset, Gset, Bset, Mode, Band, Sens, Unicorns, Save);

			}
			public void onStartTrackingTouch(SeekBar seekBar) {
				// TODO Auto-generated method stub
			}

			public void onStopTrackingTouch(SeekBar seekBar) {
				// TODO Auto-generated method stub
			}
		});
			
seekbarSens.setOnSeekBarChangeListener(new OnSeekBarChangeListener() {
			public void onProgressChanged(SeekBar seekBar, int progress,
					boolean fromUser) {
				valueSens.setText("Sensitivity: " + (progress + 1));

				Sens = progress;
				packet(Channel, Rset, Gset, Bset, Mode, Band, Sens, Unicorns, Save);

			}
			
			public void onStartTrackingTouch(SeekBar seekBar) {
				// TODO Auto-generated method stub
			}

			public void onStopTrackingTouch(SeekBar seekBar) {
				// TODO Auto-generated method stub
			}
		}); 

seekbarUnicorns.setOnSeekBarChangeListener(new OnSeekBarChangeListener() {
	public void onProgressChanged(SeekBar seekBar, int progress,
			boolean fromUser) {
		valueUnicorns.setText("Unicorns!: " + progress);

		Unicorns = progress;
		packet(Channel, Rset, Gset, Bset, Mode, Band, Sens, Unicorns, Save);

	}
	
	public void onStartTrackingTouch(SeekBar seekBar) {
		// TODO Auto-generated method stub
	}

	public void onStopTrackingTouch(SeekBar seekBar) {
		// TODO Auto-generated method stub
	}
}); 
        
    }

   

    public void colorChanged(int color) {

		int sbar_red_position = Color.red(color);
		int sbar_green_position = Color.green(color);
		int sbar_blue_position = Color.blue(color);

		seekbarRed.setProgress(sbar_red_position);
		valueRed.setText("Red: " + sbar_red_position);
		Rset = sbar_red_position;

		seekbarGreen.setProgress(sbar_green_position);
		valueGreen.setText("Green: " + sbar_green_position);
		Gset = sbar_green_position;

		seekbarBlue.setProgress(sbar_blue_position);
		valueBlue.setText("Blue: " + sbar_blue_position);
		Bset = sbar_blue_position;
		packet(Channel, Rset, Gset, Bset, Mode, Band, Sens, Unicorns, Save);
	}
	
    @Override
    public void onStart() {
        super.onStart();
    }



    @Override
	public void onResume() {
		super.onResume();
		try{
			   File f = new File(Environment.getExternalStorageDirectory()+"/Defiance.txt");
			   FileInputStream fileIS = new FileInputStream(f);
			   buf = new BufferedReader(new InputStreamReader(fileIS));
			   String readString = new String(); 
			   //just reading each line and pass it on the debugger
			   while((readString = buf.readLine())!= null){
			      address = readString;
			   }
			} catch (FileNotFoundException e) {
			   e.printStackTrace();
			} catch (IOException e){
			   e.printStackTrace();
			}

		// When this returns, it will 'know' about the server,
		// via it's MAC address.
		BluetoothDevice device = mBluetoothAdapter.getRemoteDevice(address);

		try {
			btSocket = device.createRfcommSocketToServiceRecord(MY_UUID);
		} catch (IOException e) {
		}

		mBluetoothAdapter.cancelDiscovery();

		try {
			btSocket.connect();
		} catch (IOException e) {
			try {
				btSocket.close();
			} catch (IOException e2) {
			}
		}

		// Create a data stream so we can talk to server.
		try {
			outStream = btSocket.getOutputStream();
		} catch (IOException e) {
		}
	}
	
	    public void onClickSave1(View v) throws IOException {
	    	Save = 100;
	    	packet(Channel, Rset, Gset, Bset, Mode, Band, Sens, Unicorns, Save);
	    	Save = 0;
	    	}
	    public void onClickSave2(View v) throws IOException {
	    	Save = 200;
	    	packet(Channel, Rset, Gset, Bset, Mode, Band, Sens, Unicorns, Save);
	    	Save = 0;
	    	}
	    public void onClickSave3(View v) throws IOException {
	    	Save = 300;
	    	packet(Channel, Rset, Gset, Bset, Mode, Band, Sens, Unicorns, Save);
	    	Save = 0;
	    	}
	    public void onClickSave4(View v) throws IOException {
	    	Save = 400;
	    	packet(Channel, Rset, Gset, Bset, Mode, Band, Sens, Unicorns, Save);
	    	Save = 0;
	    	}
	    public void onClickSave5(View v) throws IOException {
	    	Save = 500;
	    	packet(Channel, Rset, Gset, Bset, Mode, Band, Sens, Unicorns, Save);
	    	Save = 0;
	    	}
	    public void onClickLoad1(View v) throws IOException {
	    	Save = 10;
	    	packet(Channel, Rset, Gset, Bset, Mode, Band, Sens, Unicorns, Save);
	    	Save = 0;
	    	}
	    public void onClickLoad2(View v) throws IOException {
	    	Save = 20;
	    	packet(Channel, Rset, Gset, Bset, Mode, Band, Sens, Unicorns, Save);
	    	Save = 0;
	    	}
	    public void onClickLoad3(View v) throws IOException {
	    	Save = 30;
	    	packet(Channel, Rset, Gset, Bset, Mode, Band, Sens, Unicorns, Save);
	    	Save = 0;
	    	}
	    public void onClickLoad4(View v) throws IOException {
	    	Save = 40;
	    	packet(Channel, Rset, Gset, Bset, Mode, Band, Sens, Unicorns, Save);
	    	Save = 0;
	    	}
	    public void onClickLoad5(View v) throws IOException {
	    	Save = 50;
	    	packet(Channel, Rset, Gset, Bset, Mode, Band, Sens, Unicorns, Save);
	    	Save = 0;
	    	}
	    
	    public void onClickApply(View v) throws IOException {
	    	
	    	packet(Channel, Rset, Gset, Bset, Mode, Band, Sens, Unicorns, Save);
	    	}
	
	    @Override
		public void onPause() {
			super.onPause();

			SharedPreferences settings = getSharedPreferences(PREFS_NAME, 0);
			SharedPreferences.Editor editor = settings.edit();
			editor.putInt("seekbar_red_pref", Rset);
			editor.putInt("seekbar_green_pref", Gset);
			editor.putInt("seekbar_blue_pref", Bset);
			editor.commit();

			if (outStream != null) {
				try {
					outStream.flush();
				} catch (IOException e) {
				}
			}

			try {
				btSocket.close();
			} catch (IOException e2) {
			}
			}
	
	@Override
	public void onStop() {
		super.onStop();
	}
	
    @Override
    public void onDestroy() {
        super.onDestroy();
        // Stop the Bluetooth chat services
        
    }
 
		
	public void onClickColorPicker(View v) {
		new ColorPickerDialog(this, this, Color.rgb(Rset, Gset, Bset)).show();
		packet(Channel, Rset, Gset, Bset, Mode, Band, Sens, Unicorns, Save);
	}
	
	public void onClickRandomColor(View v) {
		    Random rnd = new Random();
		    int min = 0, max = 255;
		    int randomRed = rnd.nextInt(max - min + 1) + min;
		    int randomGreen = rnd.nextInt(max - min + 1) + min;
		    int randomBlue = rnd.nextInt(max - min + 1) + min;
		    Rset = randomRed;
		    Gset = randomGreen;
		    Bset = randomBlue;
		    new ColorPickerDialog(this, this, Color.rgb(Rset, Gset, Bset)).show();
		    packet(Channel, Rset, Gset, Bset, Mode, Band, Sens, Unicorns, Save);
	}

	
	public static void packet(int Channel, int Rset, int Gset, int Bset,int Mode, int Band, int Sens, int Unicorns, int Save) {
		int Rfin;
		int Gfin;
		int Bfin;
		int Sfin;
		int Ufin;
		Rfin = Rset * 16;
		Rfin = 4095 - Rfin;
		Gfin = Gset * 16;
		Gfin = 4095 - Gfin;
		Bfin = Bset * 16;
		Bfin = 4095 - Bfin;
		Sfin = Sens * 32;
		Ufin = Unicorns * 10;
		Ufin = 1000 - Ufin;
		Packet = "<HMG:" + Channel + ":" + Rfin + ":" + Gfin + ":" + Bfin + ":" + Mode + ":" + Band + ":" + Sfin + ":" + Ufin + ":" + Save + ">";
		byte[] msgBuffer;
        msgBuffer = Packet.getBytes();
		try {
			outStream.write(msgBuffer);
			} catch (IOException e) {
			}
		}	
	}

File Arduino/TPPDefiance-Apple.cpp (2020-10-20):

/*
This is the Skeleton code for all ATMEGA328P based Designs.
TODO: Reverse UFO Direction? EVEN BETTER!! REVERSE STRIP INSTALLATION DIRECTION
Do we need to change "two" to "two[i]"? same for "three", "four", and "five"?
*/

// Includes
#include "Tlc5940.h" // The library for the TLC5940 PWM IC
#include "tlc_fades.h" // Separate Fading Library for TLC5940
#include <EEPROM.h> // Library for interfacing to on-chip EEPROM memory
#include "EEPROMAnything.h" // Library for writing values larger than a byte (0-256) to EEPROM memory

// EEPROM Data Structure
struct config_t // "a" through "e" are channels 1-5
{
int aChn; // we save channel just to take up space, yup. (0)
int bChn; // this one always equals 1
int cChn; // this one always equals 2
int dChn; // this one always equals 3
int eChn; // this one always equals 4
int aRed; // Channel 1 Red Value (0 - 4095)
int bRed;
int cRed;
int dRed;
int eRed; // Channel 5 Red Value
int aGrn; // Channel 1 Green Value (0 - 4095)
int bGrn;
int cGrn;
int dGrn;
int eGrn; // Channel 5 Green Value
int aBlu; // Channel 1 Blue Value (0 - 4095)
int bBlu;
int cBlu;
int dBlu;
int eBlu; // Channel 5 Blue Value
int aMod; // Channel 1 Mode (0 - 83)
int bMod;
int cMod;
int dMod;
int eMod; // Channel 5 Mode
int aBnd; // Channel 1 Audio Frequency Band (0 - 6)
int bBnd;
int cBnd;
int dBnd;
int eBnd; // Channel 5 Audio Frequency Band
int aSen; // Channel 1 Audio Sensitivity (0 - 31)
int bSen;
int cSen;
int dSen;
int eSen; // Channel 5 Audio Sensitivity
int aUni; // Channel 1 User Speed Setting (0 - 1000) ANYTHING ABOVE(below?) 970(30?) IS DANGEROUS AND PRODUCES UNPREDICTABLE RESULTS!!!!!!!!!!!!!!!
int bUni;
int cUni;
int dUni;
int eUni; // Channel 5 User Speed Setting
} config;

// Pin Definitions, Port Declarations, Library Inclusions
TLC_CHANNEL_TYPE channel;
HardwareSerial BLEMini = HardwareSerial();
int analogPin = 0; // MSGEQ7 read from using analog input 0
int strobePin = 4; // MSGEQ7 strobe is attached to digital pin 2
int resetPin = 5; // MSGEQ7 reset is attached to digital pin 4
int spectrumValue[7]; // holds the a2d values from input 0

// Uart Data Variable Declarations
char inData[45]; // Buffer for the incoming data
char *inParse[45]; // Buffer for the parsed data chunks
char incomingByte; // One Character at a time
char buffer[45]; // To make room for incoming data, the previous buffer copies to this one?
int serialIn = 0; // ???
int index = 0;// Incoming data id

// Color Variable Declarations
int rojo; // user defined red value
int gren; // user defined green value
int blue; // user defined blue value
int rr; // random red value
int gg; // random green value
int bb; // random blue value
int rrr;
int ggg;
int bbb;
int colors[8][3]; // This matrix stores the color values in RGB values for ROYGBIV
int usa[3][3]; // This matrix stores the color values in RGB values for Red, White, and Blue
int off; // Used to store black instead of typing it out over and over

// Timing Variable Declarations
unsigned long ms[5]; // stores timing values for each channel
int rows[5]; // stores what row we use for rainbow flash modes
int states[5]; // stores boolean values for on off states for each channel
int two;
int twos[5]; // This value keeps track of what step we are one for two step (two color) modes
int three;
int threes[5]; // This value keeps track of what step we are one for three step (three color) modes
int four;
int fours[5]; // This value keeps track of what step we are one for four step (four color) modes
int five;
int fives[5]; // This value keeps track of what step we are one for five step (five color) modes
int fades[5];
boolean started; // packet state variable, toggled after receiving the start-of-packet character and header
boolean ended; // packet state variable, toggle after recieving the end-of-packet character
unsigned long currentMillis; // timing variable, set to the current uptime of the system in milliseconds
unsigned long previousMillis; // timg varaible, stores the last time we used current time for comparison to currentMillis
int row; // give values in setup!
int srow; // CHANGE TO USE rows[1]
int ufo; // stores which strip we should be on
int ufoLast; // the previous strip we were on, needed to move from last strip to first strip
int rLast; // Stores what Red pin we last output on for UFO modes
int gLast; // Stores what Green pin we last output on for UFO modes
int bLast; // Stores what Blue pin we last output on for UFO modes
int strips[5]; // Store what pins we should use (Red pins specifically) for each strip
int unicorns; // user defined speed setting

// Ouput and Mode Variable Declarations
int chan; // current channel (strip) AREN'T WE USING "i" FOR THIS NOW???
int mode; // user defined mode
int band; // user defined audio frequency band
int sens; // user defined audio sensitivity
int pulse;
int r; // which red channel to output on
int g; // which green channel to output on
int b; // which blue channel to ouptut on
int i; // ??? I'm pretty sure we use ONLY this, and "chan" is a waste of space...
int f; // ??? Where the "f" did I use "f" ???
int address;
int data[5][10];

// Custom Function to Load data from EEPROM based on an Address passed by the phone application
void Load(int address) // The maximum memory of 1024 bytes available to us, used by a Save/Load is 180 bytes, so each address is 200 bytes apart
	{
	EEPROM_readAnything(address, config); // Given an address, Load data from EEPROM to RAM
	data[0][1]=config.aChn;
	data[1][1]=config.bChn;
	data[2][1]=config.cChn;
	data[3][1]=config.dChn;
	data[4][1]=config.eChn;
	data[0][2]=config.aRed;
	data[1][2]=config.bRed;
	data[2][2]=config.cRed;
	data[3][2]=config.dRed;
	data[4][2]=config.eRed;
	data[0][3]=config.aGrn;
	data[1][3]=config.bGrn;
	data[2][3]=config.cGrn;
	data[3][3]=config.dGrn;
	data[4][3]=config.eGrn;
	data[0][4]=config.aBlu;
	data[1][4]=config.bBlu;
	data[2][4]=config.cBlu;
	data[3][4]=config.dBlu;
	data[4][4]=config.eBlu;
	data[0][5]=config.aMod;
	data[1][5]=config.bMod;
	data[2][5]=config.cMod;
	data[3][5]=config.dMod;
	data[4][5]=config.eMod;
	data[0][6]=config.aBnd;
	data[1][6]=config.bBnd;
	data[2][6]=config.cBnd;
	data[3][6]=config.dBnd;
	data[4][6]=config.eBnd;
	data[0][7]=config.aSen;
	data[1][7]=config.bSen;
	data[2][7]=config.cSen;
	data[3][7]=config.dSen;
	data[4][7]=config.eSen;
	data[0][8]=config.aUni;
	data[1][8]=config.bUni;
	data[2][8]=config.cUni;
	data[3][8]=config.dUni;
	data[4][8]=config.eUni;
	}
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

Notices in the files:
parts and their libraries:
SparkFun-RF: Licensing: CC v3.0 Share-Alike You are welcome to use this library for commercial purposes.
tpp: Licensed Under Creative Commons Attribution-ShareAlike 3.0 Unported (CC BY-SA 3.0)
